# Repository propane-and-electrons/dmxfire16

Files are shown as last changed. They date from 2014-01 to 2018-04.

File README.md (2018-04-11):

dmxfire16
---------

The dmxfire16 is an Arduino-compatible 16 channel solid state relay board with built-in RS-485 serial. It is the wired version of the [wifire16](https://github.com/propane-and-electrons/wifire16) - much more information on the SSR side of the board is available there.

The RS-485 connection is DMX512 compatible with any number of Arduino libraries, so the dmxfire16 can be used to control LED strip lighting or flame effects with commercial off-the-shelf lighting controllers.

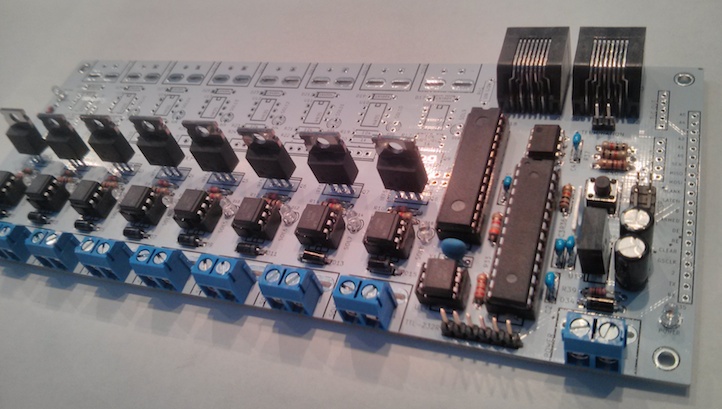
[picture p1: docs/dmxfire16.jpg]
dmxfire16 photo


### Feature Summary

* Arduino compatible
  * Use "Duemilanove or Diecimila" as the Board in the Arduino IDE
* Programmable via 6-pin FTDI header or 6-pin ICSP header
* 16 DC load channels switched via MOSFET
* RS-485 support (DMX512 compatible) via 8P8C connectors
* Termination resistor and jumper for serial connection
* All ATMega I/O pins are broken out on the board
* DC load power is optoisolated from the control system power
* Power connectors use 5mm screw terminals or Anderson Powerpole connectors
* Load power status is reported to the microcontroller via an optoisolated input pin
* Output power channels are controlled with a TLC5940 constant current driver that works like a shift register
* Each output channel has a status LED for easy debugging
* TLC5940 control lines are broken out to input/output headers, so boards can be chained without additional control systems

### Documents

* [Schematic](docs/dmxfire16-schematic.pdf)
* [Bill of Materials](docs/dmxfire16-BOM.csv)

### DMX Details

* The [DMXSerial](http://www.mathertel.de/Arduino/DMXSerial.aspx) library can be used.
* **A** from the MAX-485 is positive signal, and goes to RJ-45 pin 1 / XLR pin 3.
* **B** from the MAX-485 is negative signal (aka signal invert), and goes to RJ-45 pin 2 / XLR pin 2.
* Many receivers implement `A-B` in hardware, so if these pins are swapped DMX _is unlikely to work_.

To send DMX data, `CTRLDE` (mapped to Arduino digital pin 6) must be set high:

```
  pinMode(6, OUTPUT);
  digitalWrite(6, HIGH);
```

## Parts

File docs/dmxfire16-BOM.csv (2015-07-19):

Designator | Package | Quantity | Part | Digi-Key Part
C1,C2,C3,C4,C7 | C2 | 5 | 0.1uF | 399-4209-ND
C5,C6 | C1V5 | 2 | 47uF | P13464-ND
C8,C9 | C2 | 2 | 1uF | 445-8614-ND
D2,D4,D6,D8,D10,D12,D14,D16,D18,D20,D22,D24,D26,D28,D30,D32,D33,D35 | LED-3MM | 18 | 3mm LED | 754-1606-ND
D1,D3,D5,D7,D9,D11,D13,D15,D17,D19,D21,D23,D25,D27,D29,D31 | D3 | 17 | 1N4004 | 641-1311-1-ND
J1,J2 | RJ45_8 | 2 | 8P8C | 609-1046-ND
JP1,JP2,JP3,P18,P19,P20 | PIN_ARRAY_2X1, SIL-5,SIL-6 | 22 | header pins | A34253-40-ND
P1-P17,P25 | PP-2H-5MMSCREWTERM | 18 | 5mm screw terminal or Anderson Powerpole connector | ED2600-ND
P21 | pin_array_3x2 | 3 | 2x header pins | A34344-40-ND
Q1-Q16 | TO220GDS_VERT | 16 | IRF510 | IRF510PBF-ND
R1,R3,R5,R7,R9,R11,R13,R15,R17,R19,R21,R23,R25,R27,R29,R31,R36,R37,R38 | R3 | 19 | 10k | 10KQBK-ND
R2,R4,R6,R8,R10,R12,R14,R16,R18,R20,R22,R24,R26,R28,R30,R32,R34,R39 | R3 | 18 | 1k | 1.0KQBK-ND
R33 | R3 | 1 | 2.2k | 2.2KQBK-ND
R35 | R3 | 1 | 4k | not in stock?!
R40 | R3 | 1 | 120 | 120QBK-ND
R41 | R3-5 | 1 | 100 1/2W | 100H-ND
SW1 | SW-6MM | 1 | momentary pushbutton | SW400-ND
U1-U17 | DIP-6__300 | 17 | 4N35 | 516-1557-5-ND
XU1-XU17 | 6-DIP socket | 17 | 6DIP | A120346-ND
U18 | DIP-28__300 | 1 | TLC5940 | 296-17732-5-ND
U19 | 7805 | 1 | LM7805 | LM7805CT-ND
U20 | DIP-8__300 | 1 | SN75176 | 296-1739-5-ND
U21 | DIP-28__300 | 1 | ATMEGA328 | ATMEGA328P-PU-ND
U22 | SIL-3 | 1 | MCP1702 1V5 | MCP1702-1502E/TO-ND
Y1 | SIL-3 | 1 | 16MHz resonator | 490-1214-ND

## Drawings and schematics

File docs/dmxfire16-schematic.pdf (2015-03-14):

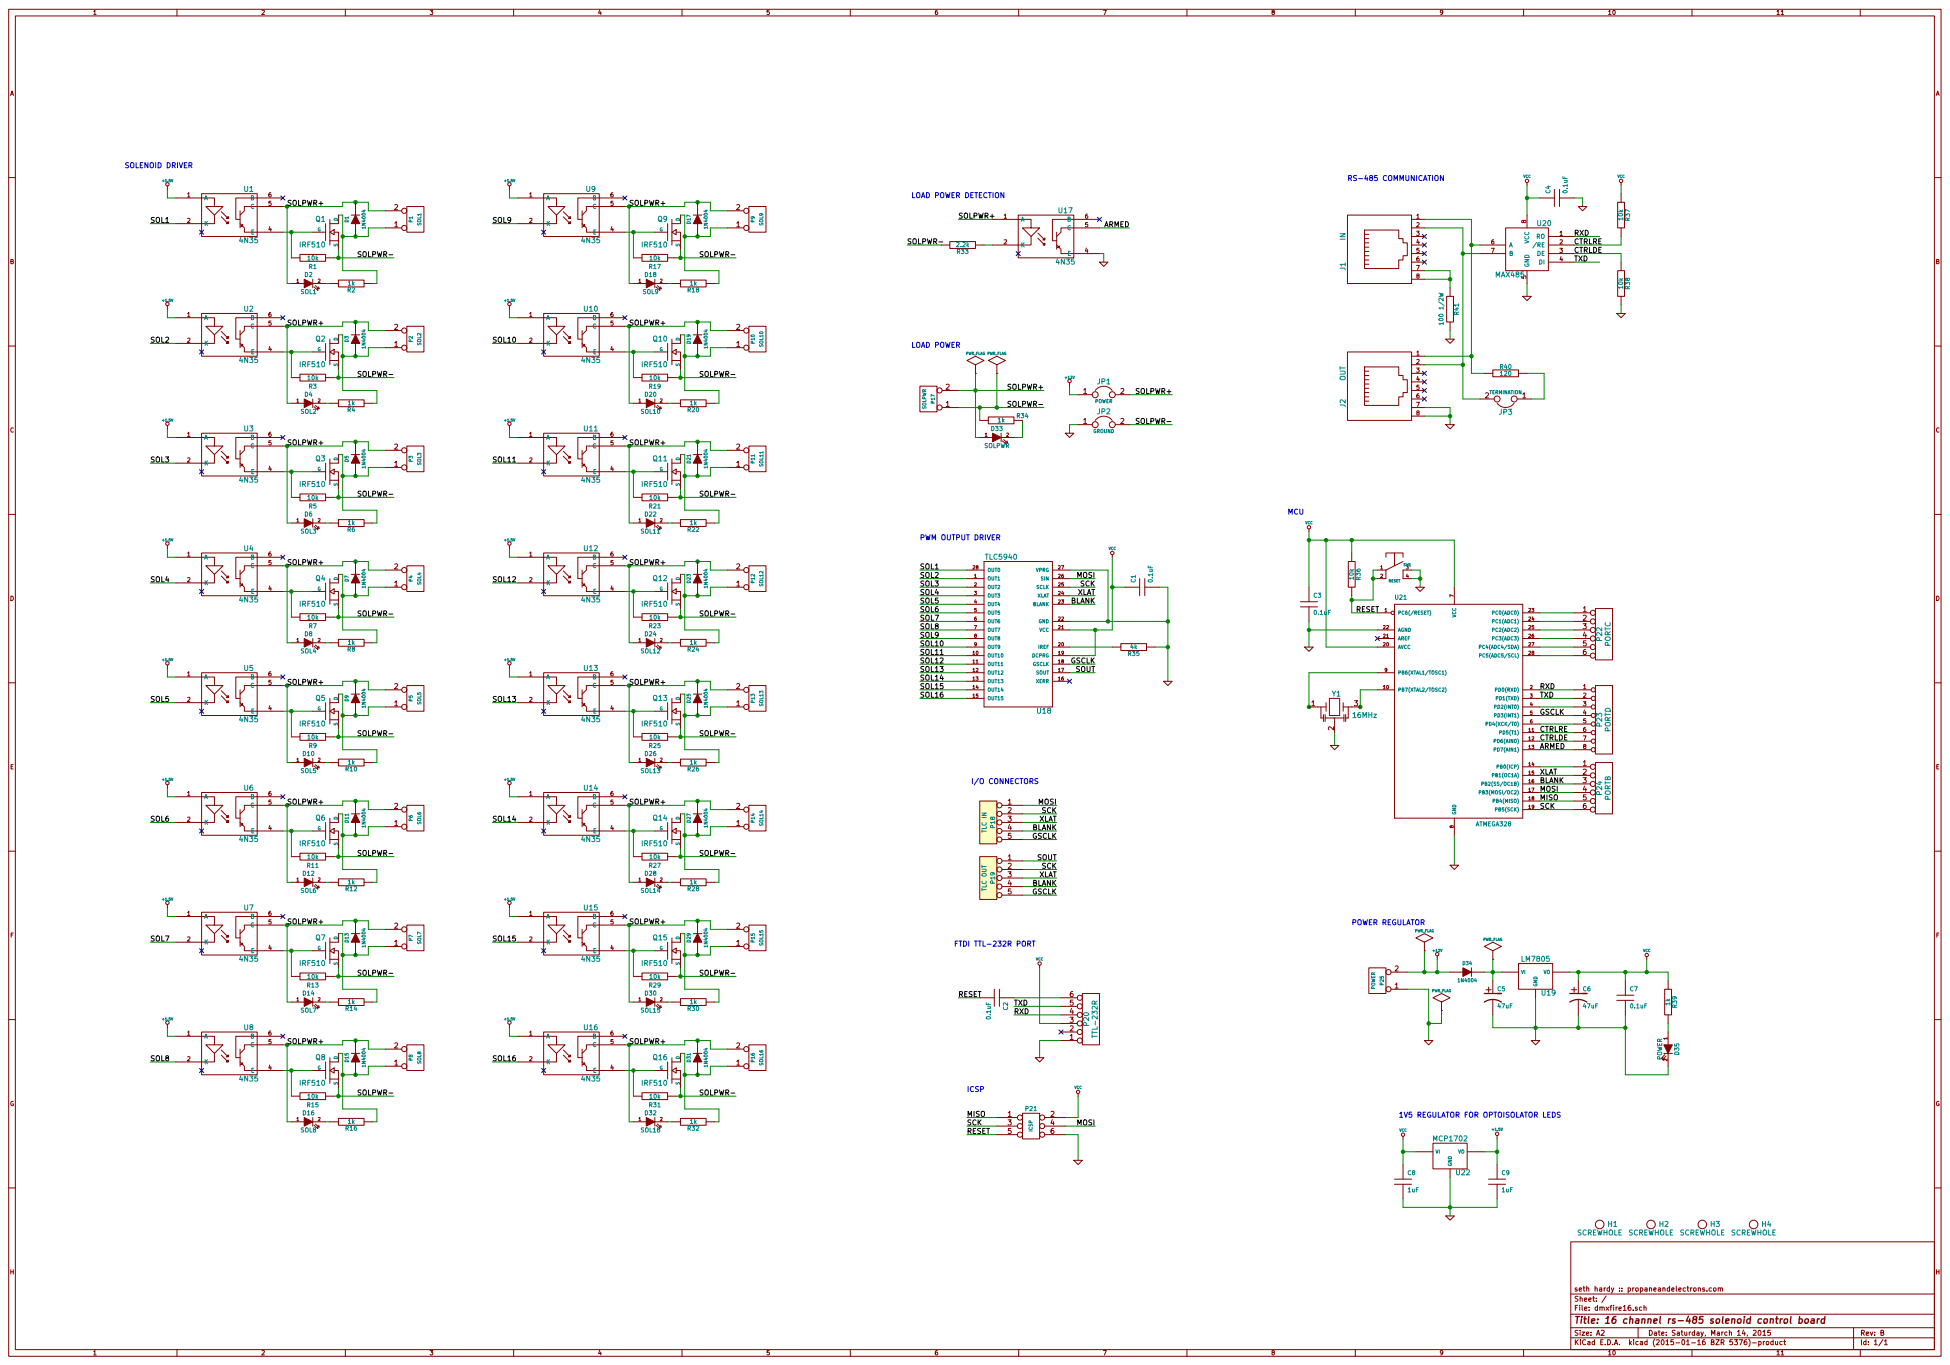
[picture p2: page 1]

H4 SCREWHOLE H3 SCREWHOLE H2 SCREWHOLE H1 SCREWHOLE

File: dmxfire16.sch Sheet: / seth hardy :: propaneandelectrons.com

Id: 1/1 Title: 16 channel rs-485 solenoid control board

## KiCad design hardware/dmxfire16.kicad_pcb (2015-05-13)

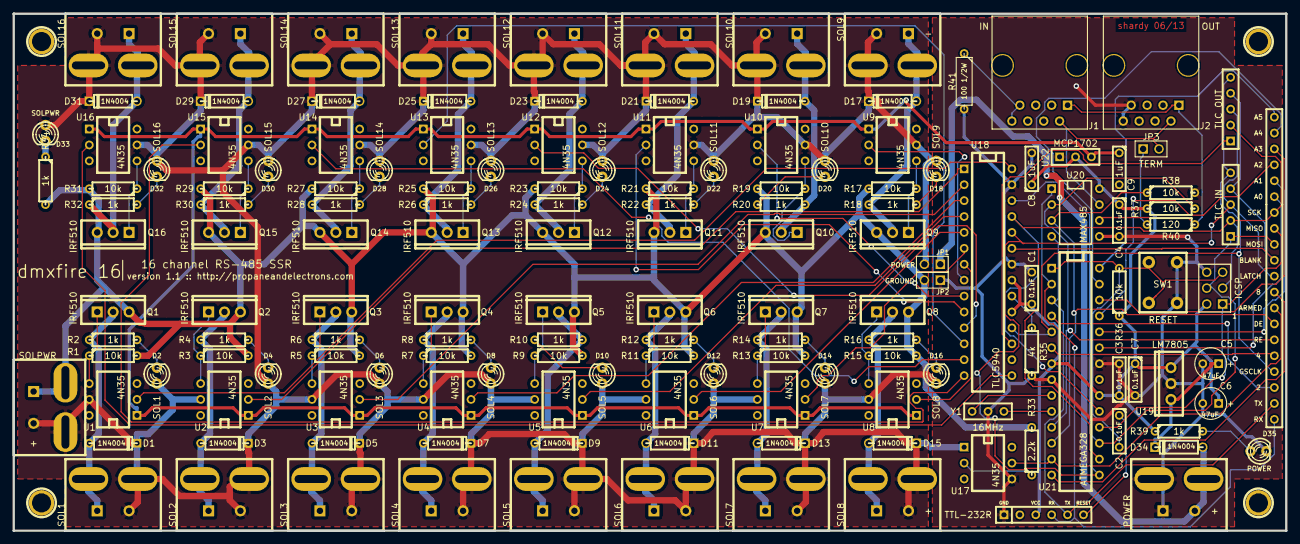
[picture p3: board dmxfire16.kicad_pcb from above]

Board: 2 copper layers, 203.2 x 82.5 mm, 159 parts (0 on the bottom side), 104 nets.

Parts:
C1, C2, C3, C4, C7: 0.1uF; C2
C5, C6: 47uF; C1V5
C8, C9: 1uF; C2
D1, D3, D5, D7, D9, D11, D13, D15, D17, D19, D21, D23, D25, D27, D29, D31, D34: 1N4004; D3
D2: SOL1; LED-3MM
D4: SOL2; LED-3MM
D6: SOL3; LED-3MM
D8: SOL4; LED-3MM
D10: SOL5; LED-3MM
D12: SOL6; LED-3MM
D14: SOL7; LED-3MM
D16: SOL8; LED-3MM
D18: SOL9; LED-3MM
D20: SOL10; LED-3MM
D22: SOL11; LED-3MM
D24: SOL12; LED-3MM
D26: SOL13; LED-3MM
D28: SOL14; LED-3MM
D30: SOL15; LED-3MM
D32: SOL16; LED-3MM
D33: SOLPWR; LED-3MM
D35: POWER; LED-3MM
H1, H2, H3, H4: SCREWHOLE; 1pin
J1: IN; RJ45_8
J2: OUT; RJ45_8
JP1: POWER; PIN_ARRAY_2X1
JP2: GROUND; PIN_ARRAY_2X1
JP3: TERM; PIN_ARRAY_2X1
P1: SOL1; PP-2H-5MMSCREWTERM
P2: SOL2; PP-2H-5MMSCREWTERM
P3: SOL3; PP-2H-5MMSCREWTERM
P4: SOL4; PP-2H-5MMSCREWTERM
P5: SOL5; PP-2H-5MMSCREWTERM
P6: SOL6; PP-2H-5MMSCREWTERM
P7: SOL7; PP-2H-5MMSCREWTERM
P8: SOL8; PP-2H-5MMSCREWTERM
P9: SOL9; PP-2H-5MMSCREWTERM
P10: SOL10; PP-2H-5MMSCREWTERM
P11: SOL11; PP-2H-5MMSCREWTERM
P12: SOL12; PP-2H-5MMSCREWTERM
P13: SOL13; PP-2H-5MMSCREWTERM
P14: SOL14; PP-2H-5MMSCREWTERM
P15: SOL15; PP-2H-5MMSCREWTERM
P16: SOL16; PP-2H-5MMSCREWTERM
P17: SOLPWR; PP-2H-5MMSCREWTERM
P18: TLC IN; SIL-5
P19: TLC OUT; SIL-5
P20: TTL-232R; SIL-6
P21: ICSP; pin_array_3x2
P22: PORTC; SIL-6
P23: PORTD; SIL-8
P24: PORTB; SIL-6
P25: POWER; PP-2H-5MMSCREWTERM
Q1, Q2, Q3, Q4, Q5, Q6, Q7, Q8, Q9, Q10, Q11, Q12, Q13, Q14, Q15, Q16: IRF510; TO220GDS_VERT
R1, R3, R5, R7, R9, R11, R13, R15, R17, R19, R21, R23, R25, R27, R29, R31, R36, R37, R38: 10k; R3
R2, R4, R6, R8, R10, R12, R14, R16, R18, R20, R22, R24, R26, R28, R30, R32, R34, R39: 1k; R3
R33: 2.2k; R3
R35: 4k; R3
R40: 120; R3
R41: 100 1/2W; R3-5
SW1: RESET; SW-6MM
U1, U2, U3, U4, U5, U6, U7, U8, U9, U10, U11, U12, U13, U14, U15, U16, U17: 4N35; DIP-6__300
U18: TLC5940; DIP-28__300
U19: LM7805; 7805
U20: MAX485; DIP-8__300
U21: ATMEGA328; DIP-28__300
U22: MCP1702; SIL-3
Y1: 16MHz; SIL-3

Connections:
+1.5V: C9.1, U1.1, U2.1, U3.1, U4.1, U5.1, U6.1, U7.1, U8.1, U9.1, U10.1, U11.1, U12.1, U13.1, U14.1, U15.1, U16.1, U22.3
+12V: D34.1, JP1.1, P25.2
/ARMED: P23.8, U17.5, U21.13
/BLANK: P18.4, P19.4, P24.3, U18.23, U21.16
/CTRLDE: P23.7, R38.1, U20.3, U21.12
/CTRLRE: P23.6, R37.2, U20.2, U21.11
/GSCLK: P18.5, P19.5, P23.4, U18.18, U21.5
/MISO: P21.1, P24.5, U21.18
/MOSI: P18.1, P21.4, P24.4, U18.26, U21.17
/RESET: C2.2, P21.5, R36.2, SW1.1, SW1.2, U21.1
/RXD: P20.4, P23.1, U20.1, U21.2
/SCK: P18.2, P19.2, P21.3, P24.6, U18.25, U21.19
/SOL1: U1.2, U18.28
/SOL2: U2.2, U18.1
/SOL3: U3.2, U18.2
/SOL4: U4.2, U18.3
/SOL5: U5.2, U18.4
/SOL6: U6.2, U18.5
/SOL7: U7.2, U18.6
/SOL8: U8.2, U18.7
/SOL9: U9.2, U18.8
/SOL10: U10.2, U18.9
/SOL11: U11.2, U18.10
/SOL12: U12.2, U18.11
/SOL13: U13.2, U18.12
/SOL14: U14.2, U18.13
/SOL15: U15.2, U18.14
/SOL16: U16.2, U18.15
/SOLPWR+: D1.2, D2.1, D3.2, D4.1, D5.2, D6.1, D7.2, D8.1, D9.2, D10.1, D11.2, D12.1, D13.2, D14.1, D15.2, D16.1, D17.2, D18.1, D19.2, D20.1, D21.2, D22.1, D23.2, D24.1, D25.2, D26.1, D27.2, D28.1, D29.2, D30.1, D31.2, D32.1, D33.1, JP1.2, P1.2, P2.2, P3.2, P4.2, P5.2, P6.2, P7.2, P8.2, P9.2, P10.2, P11.2, P12.2, P13.2, P14.2, P15.2, P16.2, P17.2, U1.5, U2.5, U3.5, U4.5, U5.5, U6.5, U7.5, U8.5, U9.5, U10.5, U11.5, U12.5, U13.5, U14.5, U15.5, U16.5, U17.1
/SOLPWR-: JP2.2, P17.1, Q1.S, Q2.S, Q3.S, Q4.S, Q5.S, Q6.S, Q7.S, Q8.S, Q9.S, Q10.S, Q11.S, Q12.S, Q13.S, Q14.S, Q15.S, Q16.S, R1.2, R3.2, R5.2, R7.2, R9.2, R11.2, R13.2, R15.2, R17.2, R19.2, R21.2, R23.2, R25.2, R27.2, R29.2, R31.2, R33.2, R34.2
/SOUT: P19.1, U18.17
/TXD: P20.5, P23.2, U20.4, U21.3
/XLAT: P18.3, P19.3, P24.2, U18.24, U21.15
GND: C1.2, C3.2, C4.2, C5.2, C6.2, C7.2, C8.2, C9.2, D35.2, J2.7, J2.8, JP2.1, P20.1, P21.6, P25.1, R35.1, R38.2, R41.2, SW1.3, SW1.4, U17.4, U18.22, U18.27, U19.2, U20.5, U21.8, U21.22, U22.1, Y1.2
unnamed: C2.1, P20.6
unnamed: C5.1, D34.2, U19.1
unnamed: D1.1, P1.1, Q1.D, R2.1
unnamed: D2.2, R2.2
unnamed: D3.1, P2.1, Q2.D, R4.1
unnamed: D4.2, R4.2
unnamed: D5.1, P3.1, Q3.D, R6.1
unnamed: D6.2, R6.2
unnamed: D7.1, P4.1, Q4.D, R8.1
unnamed: D8.2, R8.2
unnamed: D9.1, P5.1, Q5.D, R10.1
unnamed: D10.2, R10.2
unnamed: D11.1, P6.1, Q6.D, R12.1
unnamed: D12.2, R12.2
unnamed: D13.1, P7.1, Q7.D, R14.1
unnamed: D14.2, R14.2
unnamed: D15.1, P8.1, Q8.D, R16.1
unnamed: D16.2, R16.2
unnamed: D17.1, P9.1, Q9.D, R18.1
unnamed: D18.2, R18.2
unnamed: D19.1, P10.1, Q10.D, R20.1
unnamed: D20.2, R20.2
unnamed: D21.1, P11.1, Q11.D, R22.1
unnamed: D22.2, R22.2
unnamed: D23.1, P12.1, Q12.D, R24.1
unnamed: D24.2, R24.2
unnamed: D25.1, P13.1, Q13.D, R26.1
unnamed: D26.2, R26.2
unnamed: D27.1, P14.1, Q14.D, R28.1
unnamed: D28.2, R28.2
unnamed: D29.1, P15.1, Q15.D, R30.1
unnamed: D30.2, R30.2
unnamed: D31.1, P16.1, Q16.D, R32.1
unnamed: D32.2, R32.2
unnamed: D33.2, R34.1
unnamed: D35.1, R39.2
unnamed: J1.1, J2.1, R40.1, U20.6
unnamed: J1.2, J2.2, JP3.2, U20.7
unnamed: J1.7, J1.8, R41.1
unnamed: JP3.1, R40.2
unnamed: P22.1, U21.23
unnamed: P22.2, U21.24
unnamed: P22.3, U21.25
unnamed: P22.4, U21.26
unnamed: P22.5, U21.27
unnamed: P22.6, U21.28
unnamed: P23.3, U21.4
unnamed: P23.5, U21.6
unnamed: P24.1, U21.14
unnamed: Q1.G, R1.1, U1.4
unnamed: Q2.G, R3.1, U2.4
unnamed: Q3.G, R5.1, U3.4
unnamed: Q4.G, R7.1, U4.4
unnamed: Q5.G, R9.1, U5.4
unnamed: Q6.G, R11.1, U6.4
unnamed: Q7.G, R13.1, U7.4
unnamed: Q8.G, R15.1, U8.4
unnamed: Q9.G, R17.1, U9.4
unnamed: Q10.G, R19.1, U10.4
unnamed: Q11.G, R21.1, U11.4
unnamed: Q12.G, R23.1, U12.4
unnamed: Q13.G, R25.1, U13.4
unnamed: Q14.G, R27.1, U14.4
unnamed: Q15.G, R29.1, U15.4
unnamed: Q16.G, R31.1, U16.4
unnamed: R33.1, U17.2
unnamed: R35.2, U18.20
unnamed: U21.9, Y1.1
unnamed: U21.10, Y1.3
VCC: C1.1, C3.1, C4.1, C6.1, C7.1, C8.1, P20.3, P21.2, R36.1, R37.1, R39.1, U18.19, U18.21, U19.3, U20.8, U21.7, U21.20, U22.2

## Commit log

2013-03-12 initial checkin
    [dmxfire16.brd, dmxfire16.sch]
2013-03-13 standardizing directory structure
    [dmxfire16.brd, dmxfire16.sch]
2013-05-21 changing silk labels for RE and DE, kicad updating to mm?
    [dmxfire16.brd]
2013-06-22 using pp/screw footprints, rebuilt all traces
    [dmxfire16.brd, dmxfire16.sch]
2013-06-22 silkscreen fixup, putting signature on the copper
    [dmxfire16.brd]
2013-06-22 changing npth to regular drills
    [dmxfire16.brd]
2014-01-05 adding documentation
    [dmxfire16-BOM.csv]
2014-01-21 changing atmega from IC1 to U21
    [dmxfire16-BOM.csv, dmxfire16.brd, dmxfire16.sch]
2015-03-14 adding 1V5 regulator for optoisolator LED power
    [dmxfire16.brd, dmxfire16.kicad_pcb, dmxfire16.sch]
2015-03-14 removing named pin
    [dmxfire16.kicad_pcb, dmxfire16.sch]
2015-03-18 slight silk change
    [dmxfire16.kicad_pcb]
2015-05-12 adding new parts to BOM
    [dmxfire16-BOM.csv]
2015-05-12 clarification for regulator
    [dmxfire16-BOM.csv]
2015-05-13 increasing zone clearance
    [dmxfire16.kicad_pcb]
2015-07-19 Adds substitute for discontinued part.
    [dmxfire16-BOM.csv]
2018-04-04 Add note re: Board
    (Stop from having to bother Seth every time I forget this.)
